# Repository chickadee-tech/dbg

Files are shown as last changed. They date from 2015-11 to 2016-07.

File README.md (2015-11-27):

# Chickadee Tech Debug Polystack Mod #
This mod breaks out all connections in the Polystack connector. It can either be used in place of a **control** board or within a polystack.

## Documentation ##
See the [wiki](https://github.com/chickadee-tech/dbg/wiki) for documentation.

## Polystack ##
This **mod** board is part of the Polystack platform for modular microcontrol systems. More information on the platform can be found at [polystack.org](http://polystack.org).

## Support ##
If you need support with a board you own or have development questions please email support@chickadee.tech or check [chickadee.tech/support](https://chickadee.tech/support) for other ways to get support.

## Contributing ##
Please note that this project is released with a [Contributor Code of Conduct](CODE_OF_CONDUCT.md). By participating in this project you agree to abide by its terms.

### Setup ###
Components and footprints for PCB parts are not included in this repository. Instead, checkout the [chickadee-tech/kicad-libs](https://github.com/chickadee-tech/kicad-libs) repository in the same directory that this repository is checked out in. All part definitions should be relative so that they will load correctly.

### Pull requests ###
For fixes please submit a pull request to the original repository. After the pull request is merged, check the [Chickadee Tech Active Contributor Discount (ACD)](https://chickadee.tech/active-contributor) to see if you are eligible for a discount code to use on your next purchase.

### Derivatives ###
If developing your own version of the Debug board please remove all Chickadee Tech trademarks and follow the [CC-BY license](LICENSE). While not required, please consider open sourcing your modifications so others can learn from your improvements. If you do email support@chickadee.tech and we may choose to add your project to the ACD.

You may also license the Polystack logo for free by emailing support@chickadee.tech. We'll ask for your gerbers to ensure the design complies with specifications laid out [here](https://github.com/chickadee-tech/polystack/wiki) and provide written permission to use the trademark after compliance has been demonstrated.

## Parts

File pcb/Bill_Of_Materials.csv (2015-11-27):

part name | symbol | size (imp) | max current | unit price | units per build | units in stock | order total | Manufacturer ID | source url | datasheet | datasheet2
80 pin header | PORT_IN1 |  |  | $1.35 | 1 | 1 | $1.35 | DF40C-80DP-0.4V(51) | http://www.digikey.com/product-detail/en/DF40C-80DP-0.4V(51)/H11632CT-ND/1969511 | N | http://www.hirose.co.jp/cataloge_hp/ed_DF40_20140305.pdf | Total Base Cost | $12.20
80 pin receptacle (2.0mm) | PORT_OUT1 |  |  | $1.90 | 1 | 2 | $1.90 | DF40C(2.0)-80DS-0.4V(51) | http://www.digikey.com/product-detail/en/DF40C(2.0)-80DS-0.4V(51)/H11773CT-ND/2178736 | N | http://www.hirose.co.jp/cataloge_hp/ed_DF40_20140305.pdf
AND/OR gate | PORT_ANDOR1 |  |  | $0.25 | 1 | 2 | $0.25 | SN74LVC1G0832DCKR | http://www.digikey.com/product-detail/en/SN74LVC1G0832DCKR/296-18754-1-ND/863884 |  | http://www.ti.com/lit/ds/symlink/sn74lvc1g0832.pdf
multifunction gate | PORT_XOR1, PORT_INV1 |  |  | $0.14 | 2 | 6 | $0.28 | SN74LVC1G58DCKR | http://www.digikey.com/product-detail/en/SN74LVC1G58DCKR/296-15577-1-ND/571153 |  | http://www.ti.com/lit/ds/symlink/sn74lvc1g58.pdf
64kbit eeprom | PORT_IC1 |  |  | $0.61 | 1 | 2 | $0.61 | AT24CS64-MAHM-T | http://www.digikey.com/product-detail/en/AT24CS64-MAHM-T/AT24CS64-MAHM-TCT-ND/4292118 | N | http://www.atmel.com/images/atmel-8870-seeprom-at24cs64-datasheet.pdf
R 10k | PORT_R1 |  |  | $0.01 | 1 | 979 | $0.01 | RC0603FR-0710KL | http://www.digikey.com/product-detail/en/RC0603FR-0710KL/311-10.0KHRCT-ND/729827 | MF-RES-0603-10K | http://www.yageo.com/NewPortal/yageodocoutput?fileName=/pdf/R-Chip/PYu-RC_Group_51_RoHS_L_3.pdf
C 0.1uF | PORT_C1 |  |  | $0.02 | 1 | 400 | $0.02 | C0603C104K4RACTU | http://www.digikey.com/product-detail/en/C0603C104K4RACTU/399-1096-1-ND/411371 | MF-CAP-0603-0.1uF | http://www.kemet.com/docfinder?Partnumber=C0603C104K4RACTU
green led | D1 |  |  | $0.19 | 1 | 83 | $0.19 | LTST-C190KGKT | http://www.digikey.com/product-detail/en/LTST-C190KGKT/160-1435-1-ND/386814 | Y | http://optoelectronics.liteon.com/upload/download/DS22-2000-074/S_110_LTST-C190KGKT.pdf
yellow led | D2 |  |  | $0.20 | 1 | 87 | $0.20 | LTST-C190KSKT | http://www.digikey.com/product-detail/en/LTST-C190KSKT/160-1437-1-ND/386818 | N | http://optoelectronics.liteon.com/upload/download/DS-22-99-0189/S_110_LTST-C190KSKT.pdf
red led | D3 |  |  | $0.19 | 1 | 71 | $0.19 | LTST-C190KRKT | http://www.digikey.com/product-detail/en/LTST-C190KRKT/160-1436-1-ND/386816 | MF-LED-0603-RED | http://optoelectronics.liteon.com/upload/download/DS-22-99-0151/S_110_LTST-C190KRKT.pdf
R 1k | R1, R2, R3 |  |  | $0.01 | 3 | 993 | $0.03 | RC0603FR-071KL | http://www.digikey.com/product-detail/en/RC0603FR-071KL/311-1.00KHRCT-ND/729790 | MF-RES-0603-1K | http://www.yageo.com/NewPortal/yageodocoutput?fileName=/pdf/R-Chip/PYu-RC_Group_51_RoHS_L_3.pdf
R 10k | R4, R5, R6, R9, R10 |  |  | $0.01 | 5 | 979 | $0.05 | RC0603FR-0710KL | http://www.digikey.com/product-detail/en/RC0603FR-0710KL/311-10.0KHRCT-ND/729827 | MF-RES-0603-10K | http://www.yageo.com/NewPortal/yageodocoutput?fileName=/pdf/R-Chip/PYu-RC_Group_51_RoHS_L_3.pdf
R 0 | R7, R8 |  |  | $0.00 | 2 | 92 | $0.01 | RC0603JR-070RL | http://www.digikey.com/product-search/en?keywords=311-0.0grct-nd
Debug board | PCB |  |  | $6.70 | 1 | 2 | $6.70 | CKD-DBG-V2 |  | N
~2mm Spacer | Offboard |  |  | $0.08 | 5 | 100 | $0.42 | 908-080 | http://www.mouser.com/ProductDetail/Bivar/908-080/?qs=sGAEpiMZZMtU66%252bVMtdfbpPy1E%252bha670 | N | http://www.bivar.com/Portals/0/Products/d.ashx?f=/Portals/0/products/9XX-XXX.pdf

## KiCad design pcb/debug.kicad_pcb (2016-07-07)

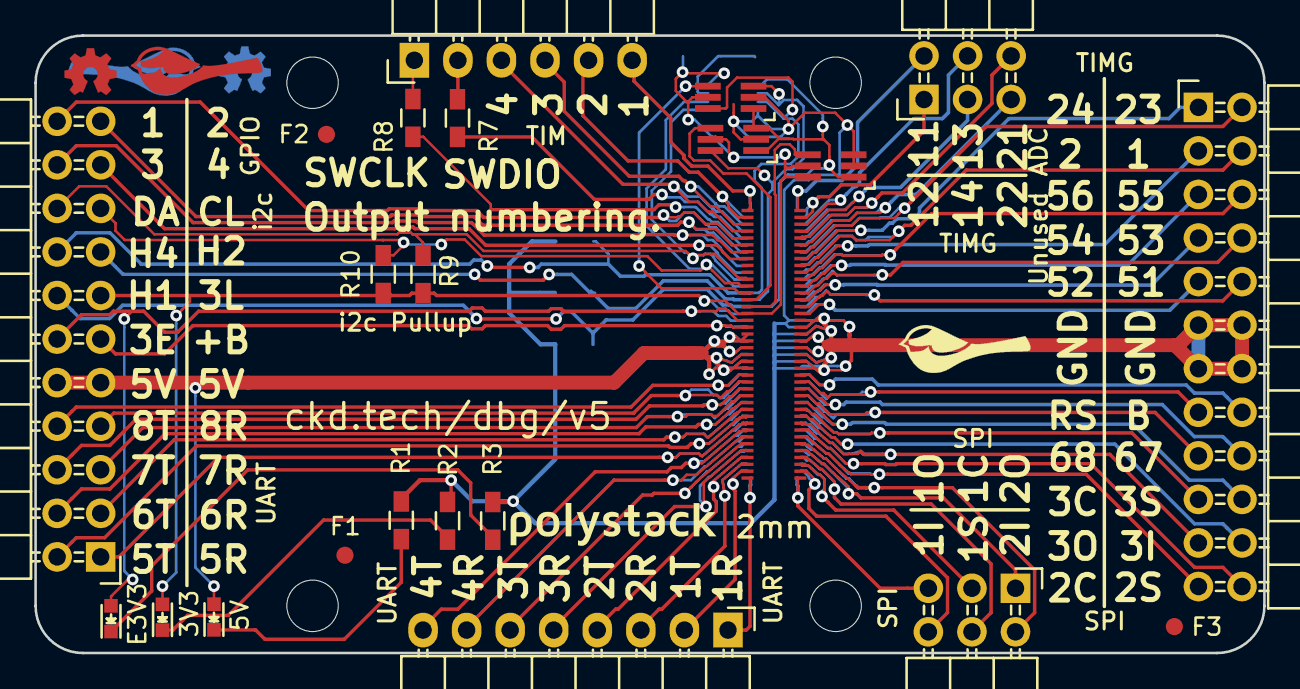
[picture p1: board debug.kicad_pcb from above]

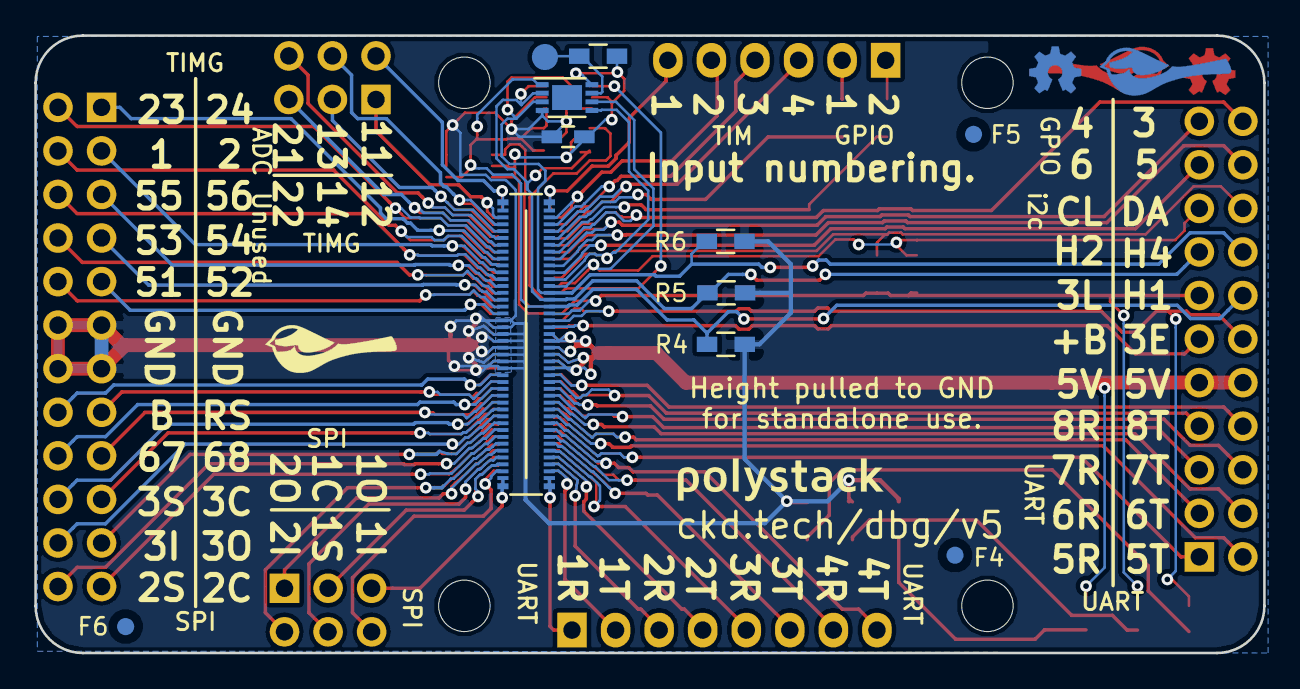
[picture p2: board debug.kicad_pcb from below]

Board: 2 copper layers, 71.7 x 36.0 mm, 36 parts (12 on the bottom side), 77 nets.

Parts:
D1: Green; LED-0603
D2: Yellow; LED-0603
D3: Red; LED-0603
F1, F2, F3, F4, F5, F6: 1mm; Fiducial
P1: CONN_01X06; Pin_Header_Angled_1x06
P2: CONN_02X11; Pin_Header_Angled_2x11
P3: CONN_01X08; Pin_Header_Angled_1x08
P4, P6: CONN_02X03; Pin_Header_Angled_2x03
P5: CONN_02X12; Pin_Header_Angled_2x12
PORT_ANDOR1: SN74LVC1G0832; SC-70-6_Handsoldering
PORT_C1: 0.1uF; C_0603_HandSoldering
PORT_IC1: AT24CS02-MAHM; DFN-8-1EP_3x2mm_Pitch0.5mm
PORT_IN1: CKD_SANDWICH; DF40-80pin-Header
PORT_INV1: SN74LVC1G58; SC-70-6_Handsoldering
PORT_OUT1: CKD_SANDWICH; DF40-3-4mm-80pin-Receptacle
PORT_P1: CONN_01X01; Measurement_Point_Round-SMD-Pad_Small
PORT_R1: 10k; R_0603_HandSoldering
PORT_XOR1: SN74LVC1G58; SC-70-6_Handsoldering
R1, R2, R3: 1k; R_0603_HandSoldering
R4, R5, R6, R9, R10: 10k; R_0603_HandSoldering
R7, R8: 470; R_0603_HandSoldering
svg2mod, svg2mod#2: G***; polystack-bold-0.625

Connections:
+5V: D1.2, P2.9, P2.10, PORT_IN1.19, PORT_IN1.20, PORT_IN1.21, PORT_IN1.22, PORT_IN1.23, PORT_IN1.24, PORT_OUT1.19, PORT_OUT1.20, PORT_OUT1.21, PORT_OUT1.22, PORT_OUT1.23, PORT_OUT1.24
/ExpansionPort/3V3_0.3A_E: D3.2, P2.12, PORT_IN1.17, PORT_OUT1.17
/ExpansionPort/3V3_0.3A_LL: D2.2, P2.13, PORT_ANDOR1.5, PORT_C1.1, PORT_IC1.8, PORT_IN1.16, PORT_INV1.5, PORT_INV1.6, PORT_OUT1.16, PORT_R1.2, PORT_XOR1.5, R9.1, R10.1
/ExpansionPort/+BATT: P2.11, PORT_IN1.18, PORT_OUT1.18
/ExpansionPort/ADC1: P5.4, PORT_IN1.49, PORT_OUT1.49
/ExpansionPort/ADC2: P5.3, PORT_IN1.50, PORT_OUT1.50
/ExpansionPort/BOOT: P5.16, PORT_IN1.65, PORT_OUT1.65
/ExpansionPort/CAN_HI: P5.18, PORT_IN1.67, PORT_OUT1.67
/ExpansionPort/CAN_LO: P5.17, PORT_IN1.68, PORT_OUT1.68
/ExpansionPort/GPIO1: PORT_IN1.5, R7.2
/ExpansionPort/GPIO2: PORT_IN1.6, R8.2
/ExpansionPort/GPIO3: P2.22, PORT_IN1.7, PORT_OUT1.5
/ExpansionPort/GPIO4: P2.21, PORT_IN1.8, PORT_OUT1.6
/ExpansionPort/GPIO5: P2.20, PORT_IN1.9, PORT_OUT1.7
/ExpansionPort/GPIO6: P2.19, PORT_IN1.10, PORT_OUT1.8
/ExpansionPort/HEIGHT_1: P2.14, PORT_ANDOR1.1, PORT_IC1.1, PORT_IN1.15, PORT_INV1.1, PORT_XOR1.1, PORT_XOR1.3, R4.1
/ExpansionPort/HEIGHT_2: P2.15, PORT_ANDOR1.3, PORT_IC1.2, PORT_IN1.14, PORT_XOR1.6, R5.1
/ExpansionPort/HEIGHT_4: P2.16, PORT_ANDOR1.6, PORT_IC1.3, PORT_IN1.13, R6.1
/ExpansionPort/NEW_HEIGHT_1: PORT_INV1.4, PORT_OUT1.15
/ExpansionPort/NEW_HEIGHT_2: PORT_OUT1.14, PORT_XOR1.4
/ExpansionPort/NEW_HEIGHT_4: PORT_ANDOR1.4, PORT_OUT1.13
/ExpansionPort/RESET: P5.15, PORT_IN1.66, PORT_OUT1.66
/ExpansionPort/SDMMC1_CK: P5.10, PORT_IN1.55, PORT_OUT1.55
/ExpansionPort/SDMMC1_CMD: P5.9, PORT_IN1.56, PORT_OUT1.56
/ExpansionPort/SDMMC1_D0: P5.6, PORT_IN1.51, PORT_OUT1.51
/ExpansionPort/SDMMC1_D1: P5.5, PORT_IN1.52, PORT_OUT1.52
/ExpansionPort/SDMMC1_D2: P5.8, PORT_IN1.53, PORT_OUT1.53
/ExpansionPort/SDMMC1_D3: P5.7, PORT_IN1.54, PORT_OUT1.54
/ExpansionPort/SPI1_MISO: P6.6, PORT_IN1.79, PORT_OUT1.79
/ExpansionPort/SPI1_MOSI: P6.5, PORT_IN1.80, PORT_OUT1.80
/ExpansionPort/SPI1_NSS: P6.4, PORT_IN1.77, PORT_OUT1.77
/ExpansionPort/SPI1_SCK: P6.3, PORT_IN1.78, PORT_OUT1.78
/ExpansionPort/SPI2_MISO: P6.2, PORT_IN1.75, PORT_OUT1.75
/ExpansionPort/SPI2_MOSI: P6.1, PORT_IN1.76, PORT_OUT1.76
/ExpansionPort/SPI2_NSS: P5.24, PORT_IN1.73, PORT_OUT1.73
/ExpansionPort/SPI2_SCK: P5.23, PORT_IN1.74, PORT_OUT1.74
/ExpansionPort/SPI3_MISO: P5.22, PORT_IN1.71, PORT_OUT1.71
/ExpansionPort/SPI3_MOSI: P5.21, PORT_IN1.72, PORT_OUT1.72
/ExpansionPort/SPI3_NSS: P5.20, PORT_IN1.69, PORT_OUT1.69
/ExpansionPort/SPI3_SCK: P5.19, PORT_IN1.70, PORT_OUT1.70
/ExpansionPort/TIM1: P1.6, PORT_IN1.1, PORT_OUT1.1
/ExpansionPort/TIM2: P1.5, PORT_IN1.2, PORT_OUT1.2
/ExpansionPort/TIM3: P1.4, PORT_IN1.3, PORT_OUT1.3
/ExpansionPort/TIM4: P1.3, PORT_IN1.4, PORT_OUT1.4
/ExpansionPort/TIMG1_CH1: P4.2, PORT_IN1.41, PORT_OUT1.41
/ExpansionPort/TIMG1_CH2: P4.1, PORT_IN1.42, PORT_OUT1.42
/ExpansionPort/TIMG1_CH3: P4.4, PORT_IN1.43, PORT_OUT1.43
/ExpansionPort/TIMG1_CH4: P4.3, PORT_IN1.44, PORT_OUT1.44
/ExpansionPort/TIMG2_CH1: P4.6, PORT_IN1.45, PORT_OUT1.45
/ExpansionPort/TIMG2_CH2: P4.5, PORT_IN1.46, PORT_OUT1.46
/ExpansionPort/TIMG2_CH3: P5.2, PORT_IN1.47, PORT_OUT1.47
/ExpansionPort/TIMG2_CH4: P5.1, PORT_IN1.48, PORT_OUT1.48
/ExpansionPort/UART1_RX: P3.1, PORT_IN1.40, PORT_OUT1.40
/ExpansionPort/UART1_TX: P3.2, PORT_IN1.39, PORT_OUT1.39
/ExpansionPort/UART2_RX: P3.3, PORT_IN1.38, PORT_OUT1.38
/ExpansionPort/UART2_TX: P3.4, PORT_IN1.37, PORT_OUT1.37
/ExpansionPort/UART3_RX: P3.5, PORT_IN1.36, PORT_OUT1.36
/ExpansionPort/UART3_TX: P3.6, PORT_IN1.35, PORT_OUT1.35
/ExpansionPort/UART4_RX: P3.7, PORT_IN1.34, PORT_OUT1.34
/ExpansionPort/UART4_TX: P3.8, PORT_IN1.33, PORT_OUT1.33
/ExpansionPort/UART5_RX: P2.1, PORT_IN1.32, PORT_OUT1.32
/ExpansionPort/UART5_TX: P2.2, PORT_IN1.31, PORT_OUT1.31
/ExpansionPort/UART6_RX: P2.3, PORT_IN1.30, PORT_OUT1.30
/ExpansionPort/UART6_TX: P2.4, PORT_IN1.29, PORT_OUT1.29
/ExpansionPort/UART7_RX: P2.5, PORT_IN1.28, PORT_OUT1.28
/ExpansionPort/UART7_TX: P2.6, PORT_IN1.27, PORT_OUT1.27
/ExpansionPort/UART8_RX: P2.7, PORT_IN1.26, PORT_OUT1.26
/ExpansionPort/UART8_TX: P2.8, PORT_IN1.25, PORT_OUT1.25
/ExpansionPort/i2c_SCL: P2.17, PORT_IC1.6, PORT_IN1.12, PORT_OUT1.12, R10.2
/ExpansionPort/i2c_SDA: P2.18, PORT_IC1.5, PORT_IN1.11, PORT_OUT1.11, R9.2
GNDPWR: P5.11, P5.12, P5.13, P5.14, PORT_ANDOR1.2, PORT_C1.2, PORT_IC1.4, PORT_IN1.57, PORT_IN1.58, PORT_IN1.59, PORT_IN1.60, PORT_IN1.61, PORT_IN1.62, PORT_IN1.63, PORT_IN1.64, PORT_INV1.2, PORT_INV1.3, PORT_OUT1.57, PORT_OUT1.58, PORT_OUT1.59, PORT_OUT1.60, PORT_OUT1.61, PORT_OUT1.62, PORT_OUT1.63, PORT_OUT1.64, PORT_XOR1.2, R1.2, R2.2, R3.2, R4.2, R5.2, R6.2
unnamed: D1.1, R1.1
unnamed: D2.1, R2.1
unnamed: D3.1, R3.1
unnamed: P1.1, R8.1
unnamed: P1.2, R7.1
unnamed: PORT_IC1.7, PORT_P1.1, PORT_R1.1

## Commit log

2015-11-27 Debug board for chickadee v1.
    [Bill_Of_Materials.csv, ExpansionPort.sch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]
2016-01-07 Debug v2 with pin function labels and add inline resistors for SWD lines.
    [ExpansionPort.sch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]
2016-04-07 More logos and i2c label.
    [ExpansionPort.sch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]
2016-04-13 Rebrand everything to Polystack and increment versions.
    [debug.kicad_pcb]
2016-04-16 Final gerbers for test manufacturing run.
    [ExpansionPort.sch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]
2016-06-07 Update polystack logo to bold variant and bump version number.
    [debug.kicad_pcb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]
2016-07-07 Add license information to many files. PCB design files are CC-BY and code is MIT license.
    [ExpansionPort.sch, debug.kicad_pcb, debug.sch]
2016-07-07 Convert to relative component and footprint paths.
    [ExpansionPort.sch, debug.sch]

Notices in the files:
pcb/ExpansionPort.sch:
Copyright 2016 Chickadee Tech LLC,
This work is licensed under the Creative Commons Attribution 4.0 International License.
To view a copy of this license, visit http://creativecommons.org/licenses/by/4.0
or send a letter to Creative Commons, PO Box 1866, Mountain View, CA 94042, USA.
